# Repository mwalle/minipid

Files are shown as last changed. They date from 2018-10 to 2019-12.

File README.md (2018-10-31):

# minipid - an attiny based heating controller

minipid is an open source hardware and software PI controller. It's design
goal is to be cheap and easy to build. It was originally developed for the
Rancilio Siliva.

## Warning

This project uses dangerous mains voltage. Be careful!

## Features

 * cheap
 * configurable parameters, like target temperature, Kp and Ki and controlling range
 * auto off
 * built in self test
 * configuration interface on the serial line
 * display support
 * ISP support
 * fast PI controller
 * emergency off
 * error blinking, if no display is connected
 * easy to use, easy to built
 * dump parameters like temperature and output value to serial console
 * automatically detects connected display
 * open hardware and open source software

## License

The firmware is licensed under the GNU Public License version 2 and the
hardware is licensed under CERN OHL v.1.2. See `COPYING.firmware` and
`COPYING.hardware` for the complete license.

## Hardware Errata

 - [ ] SDA and SCL pull-downs are missing

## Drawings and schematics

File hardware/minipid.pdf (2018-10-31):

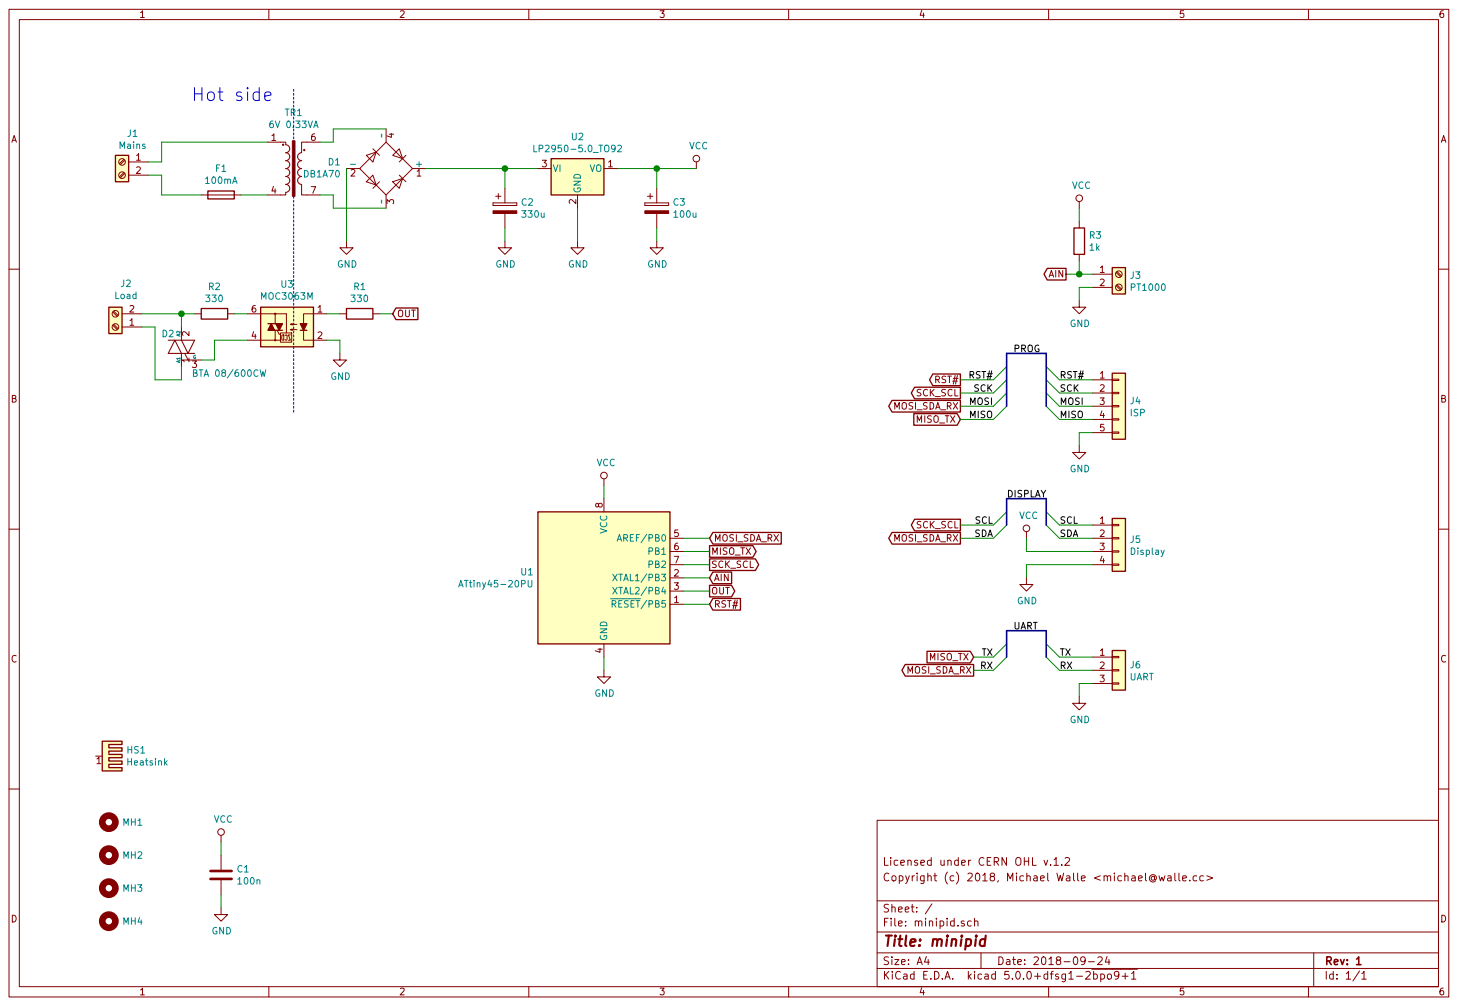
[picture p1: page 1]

SCK_SCL RST# RST# SCK MOSI MISO

ISP RST# MISO MOSI SCK

Licensed under CERN OHL v.1.2
File: minipid.sch Sheet: / Copyright (c) 2018, Michael Walle <michael@walle.cc>

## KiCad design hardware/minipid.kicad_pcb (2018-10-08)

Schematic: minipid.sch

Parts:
C1: 100n; C_Disc_D4.3mm_W1.9mm_P5.00mm
C2: 330u; CP_Radial_D8.0mm_P3.50mm
C3: 100u; CP_Radial_D6.3mm_P2.50mm
D1: DB1A70; Diode_Bridge_DIP-4_W7.62mm_P5.08mm
D2: BTA 08/600BW; TO-220-3_Horizontal_TabDown
F1: 100mA; Fuseholder_TR5_Littlefuse_No560_No460
HS1: Heatsink; Heatsink_35x26mm_1xFixation3mm_Fischer-SK486-35
J1: Mains; TerminalBlock_RND_205-00001_1x02_P5.00mm_Horizontal
J2: Load; TerminalBlock_RND_205-00001_1x02_P5.00mm_Horizontal
J3: PT1000; TerminalBlock_RND_205-00001_1x02_P5.00mm_Horizontal
J4: ISP; PinHeader_1x05_P2.54mm_Vertical
J5: Display; PinHeader_1x04_P2.54mm_Vertical
J6: UART; PinHeader_1x03_P2.54mm_Vertical
MH1, MH2, MH3, MH4: MountingHole; MountingHole_3.2mm_M3
R1, R2: 330; R_Axial_DIN0207_L6.3mm_D2.5mm_P10.16mm_Horizontal
R3: 1k; R_Axial_DIN0207_L6.3mm_D2.5mm_P10.16mm_Horizontal
TR1: 6V 0.33VA; Transformer_Breve_TEZ-22x24
U1: ATtiny45-20PU; DIP-8_W7.62mm
U2: LP2950-5.0_TO92; TO-92_Inline
U3: MOC3063M; DIP-6_W7.62mm

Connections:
AIN: J3.1, R3.2, U1.2 (XTAL1/PB3)
GND: C1.2, C2.2, C3.2, D1.2, J3.2, J4.5, J5.4, J6.3, U1.4 (GND), U2.2 (GND), U3.2
MISO_TX: J4.4, J6.1, U1.6 (PB1)
MOSI_SDA_RX: J4.3, J5.2, J6.2, U1.5 (AREF/PB0)
unnamed: C2.1, D1.1, U2.3 (VI)
unnamed: D1.3, TR1.7
unnamed: D1.4, TR1.6
unnamed: D2.1, J2.1
unnamed: D2.2, J2.2, R2.1
unnamed: D2.3, U3.4
unnamed: F1.1, J1.2
unnamed: F1.2, TR1.4
unnamed: J1.1, TR1.1
unnamed: R1.1, U3.1
unnamed: R2.2, U3.6
OUT: R1.2, U1.3 (XTAL2/PB4)
RST#: J4.1, U1.1 (~RESET~/PB5)
SCK_SCL: J4.2, J5.1, U1.7 (PB2)
VCC: C1.1, C3.1, J5.3, R3.1, U1.8 (VCC), U2.1 (VO)

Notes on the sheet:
Hot side

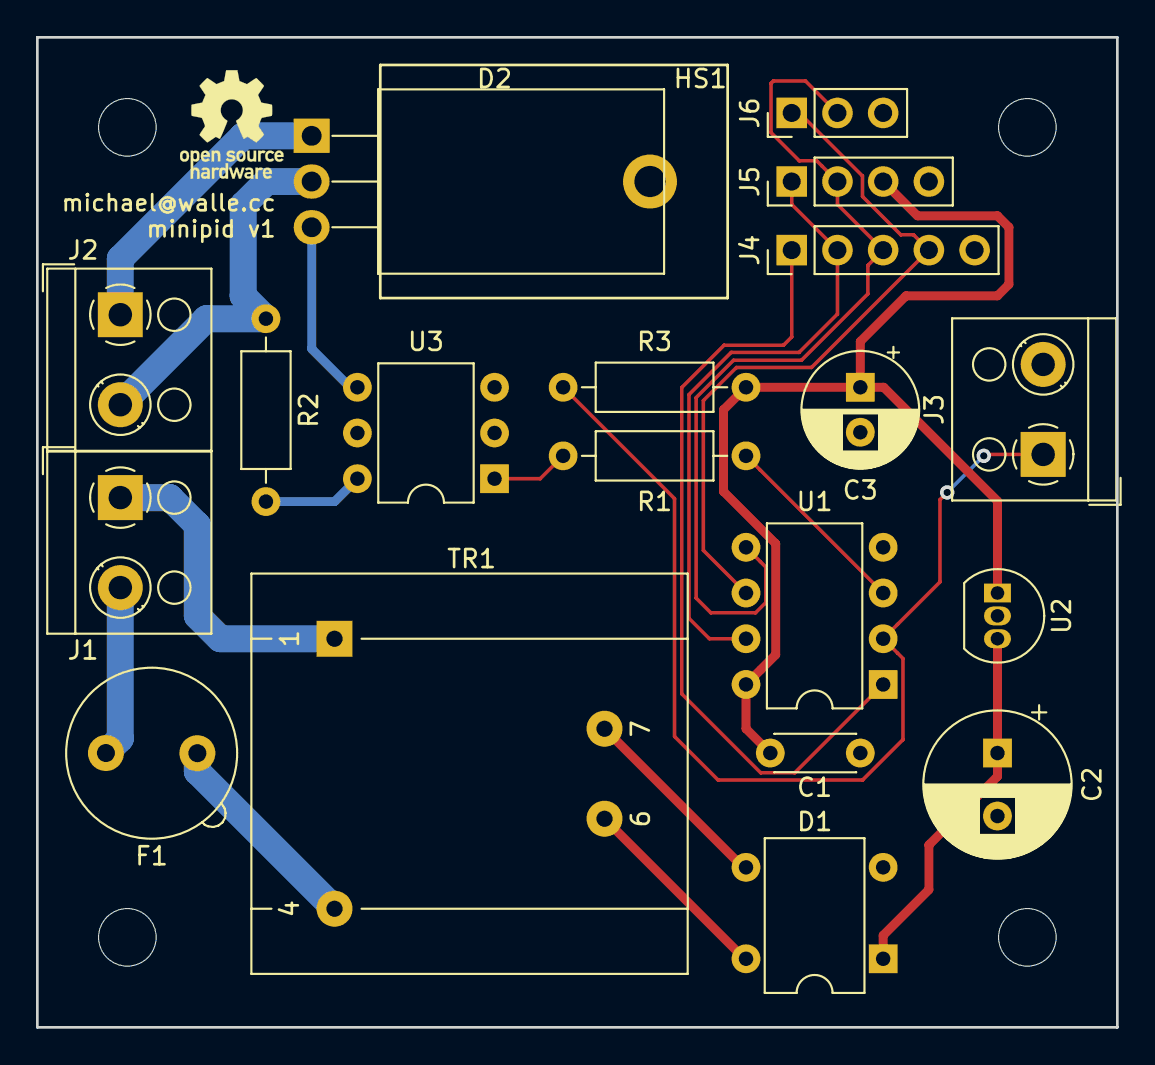
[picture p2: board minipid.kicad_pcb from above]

Board: 2 copper layers, 60.0 x 55.0 mm, 24 parts (0 on the bottom side), 19 nets.

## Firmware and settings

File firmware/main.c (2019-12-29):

/*
 * minipid - attiny-based heating controller
 * Copyright (c) 2018, Michael Walle <michael@walle.cc>
 *
 * SPDX-License-Identifier: GPL-2.0
 */

#include <stdio.h>
#include <stdbool.h>
#include <string.h>
#include <stdlib.h>
#include <avr/io.h>
#include <avr/interrupt.h>
#include <avr/pgmspace.h>
#include <util/atomic.h>
#include <util/delay.h>

#include "usi.h"
#include "adc.h"
#include "pt1000.h"
#include "pid.h"
#include "config.h"

#define VERSION "0.1"
#ifndef FORCE_CLI_ENABLED
#define FORCE_CLI_ENABLED 0
#endif

static volatile uint8_t __pwm_steps;
static void pwm_set(uint8_t steps)
{
	__pwm_steps = steps;
}

static void pwm_init(void)
{
	__pwm_steps = 0;
	PORTB &= _BV(PB4);
	DDRB |= _BV(PB4);
}

static void pwm_off(void)
{
	__pwm_steps = 0;
	PORTB &= ~_BV(PB4);
}

static volatile uint16_t __uptime;
static volatile uint32_t __millis;

uint16_t uptime(void)
{
	uint16_t _uptime;
	ATOMIC_BLOCK(ATOMIC_FORCEON) {
		_uptime = __uptime;
	}
	return _uptime;
}

uint32_t millis(void)
{
	uint32_t _millis;
	ATOMIC_BLOCK(ATOMIC_FORCEON) {
		_millis = __millis;
	}
	return _millis;
}

ISR(TIM1_COMPA_vect)
{
	static uint8_t cycle = 0;

	/* only set the pwm output of the beginning of the cycle */
	if (__pwm_steps && cycle == 0)
		PORTB |= _BV(PB4);
	else if (cycle >= __pwm_steps)
		PORTB &= ~_BV(PB4);

	__millis += 10;

	if (cycle == 99 || cycle == 199)
		__uptime++;

	if (++cycle >= 200)
		cycle = 0;
}

static void timer1_init(void)
{
	/*
	 * Setup Timer1 to 10ms (actually 9.98ms).
	 *
	 * The system clock is 8 MHz, use the 512 prescaler and a counter
	 * value of 156.
	 *
	 */
	/* CTC mode, prescaler to 512 */
	TCCR1 = _BV(CTC1) | _BV(CS13) | _BV(CS11);
	OCR1A = (F_CPU / 512 / 100);
	OCR1C = (F_CPU / 512 / 100);

	/* enable timer interrupt */
	TIMSK |= _BV(OCIE1A);
}

static void timer1_stop(void)
{
	TCCR1 = 0;
}

enum {
	ERROR_INVALID_SDA_SCL_STATE = 1,
	ERROR_SENSOR_UNCONNECTED = 2,
	ERROR_SENSOR_SHORTED = 3,
	ERROR_EMERGENCY_OFF = 4,
};

static void reset(void) __attribute__((noreturn));
static void reset(void)
{
	WDTCR = _BV(WDE);
	while (true);
}

static void configuration_mode(void)
{
	const char *buf;
	char c;

	/* turn output off */
	pwm_off();

	uart_puts_P(PSTR("Configuration mode, output disabled.\n"));

	while (true) {
again:
		uart_get_buf();
		uart_puts_P(PSTR("config> "));
		while (true) {
			uart_poll();
			c = uart_getc();

			if (c == '\r') {
				uart_putc('\n');
				break;
			}

			if (c == '\b' || c == 127) {
				uart_puts("Backspace not supported. Try again.\n");
				goto again;
			}

			/* echo back */
			uart_putc(c);
		}

		buf = uart_get_buf();
		if (buf[0] == '.') {
			config_scan_input(buf + 1);
			config_dump();
		} else if (buf[0] == '\r') {
			continue;
		} else if (!strncmp_P(buf, PSTR("reset"), 5)) {
			reset();
		} else if (!strncmp_P(buf, PSTR("dump"), 4)) {
			config_dump();
		} else if (!strncmp_P(buf, PSTR("save"), 4)) {
			uart_puts_P(PSTR("Saving config to EEPROM.\n"));
			config_save();
		} else if (!strncmp_P(buf, PSTR("exit"), 4)) {
			uart_puts_P(PSTR("Exitting config mode.\n"));
			return;
		} else if (!strncmp_P(buf, PSTR("help"), 4)) {
			uart_puts_P(PSTR(
						"Available commands:\n"
						".<P> <V> - set parameter <P> to value <V>\n"
						"dump  - show config\n"
						"save  - show config\n"
						"reset - reset controller\n"
						"exit  - show config\n"));
		} else {
			uart_puts_P(PSTR("Unknown command, try 'help'.\n"));
		}
	}
}

static void blink_errorcode(uint8_t code) __attribute__((noreturn));
static void blink_errorcode(uint8_t code)
{
	char buf[8];
	int i;

	/* turn output off */
	timer1_stop();
	PORTB &= ~_BV(PB4);

	while (true) {
		if (uart_getc() == '\r')
			configuration_mode();

		/* output error on UART */
		uart_puts_P(PSTR("ERR"));
		uart_puts(itoa(code, buf, 10));
		uart_puts_P(PSTR("\n"));

		/* two short blinks */
		for (i = 0; i < 2; i++) {
			PORTB |= _BV(PB4);
			_delay_ms(50);
			PORTB &= ~_BV(PB4);
			_delay_ms(300);
		}

		_delay_ms(500);
		/* error code */
		for (i = 0; i < code; i++) {
			PORTB |= _BV(PB4);
			_delay_ms(100);
			PORTB &= ~_BV(PB4);
			_delay_ms(500);
		}

		/* 10s pause */
		_delay_ms(10000);
	}
}

static void display_init(void)
{
	uint8_t buf;

	/* dummy transfer */
	buf = 0x00;
	twi_transfer(&buf, 1);

	/* display on, max brightness */
	buf = 0xf1;
	twi_transfer(&buf, 1);
}

static uint8_t display_digit(uint8_t i)
{
	static const uint8_t digits[] PROGMEM = {
		0b11111100,    // 0
		0b01100000,    // 1
		0b11011010,    // 2
		0b11110010,    // 3
		0b01100110,    // 4
		0b10110110,    // 5
		0b10111110,    // 6
		0b11100000,    // 7
		0b11111110,    // 8
		0b11110110,    // 9
		0b11101110,    // A
		0b00111110,    // b
		0b10011100,    // C
		0b01111010,    // d
		0b10011110,    // E
		0b10001110,    // F
		0b00000000,    // all off
		0b11000110,    // deg
	};

	return pgm_read_byte(&(digits[i]));
}

static void display_errorcode(uint8_t code)
{
	static uint8_t buf[5];

	buf[0] = 0x02;
	twi_transfer(buf, 1);

	buf[0] = '\x03';
	buf[1] = display_digit(14);
	buf[2] = display_digit(0);
	buf[3] = display_digit(0);
	buf[4] = display_digit(code % 10);

	twi_transfer(buf, 5);
}

static void display_degc(uint8_t val)
{
	static uint8_t buf[5];

	buf[0] = 0x02;
	twi_transfer(buf, 1);

	buf[0] = '\x03';
	if (val < 100)
		buf[1] = display_digit(16);
	else
		buf[1] = display_digit((val / 100) % 10);
	if (val < 10)
		buf[2] = display_digit(16);
	else
		buf[2] = display_digit((val / 10) % 10);
	buf[3] = display_digit(val % 10);
	buf[4] = display_digit(17);

	twi_transfer(buf, 5);
}

static void print_statusline(int16_t degc, int16_t pwm, bool auto_off)
{
	char buf[8];
	uart_puts(itoa(uptime(), buf, 10));
	uart_puts_P(PSTR(" "));
	uart_puts(itoa(degc / 10, buf, 10));
	uart_puts_P(PSTR("."));
	uart_puts(itoa(degc % 10, buf, 10));
	uart_puts_P(PSTR(" "));
	uart_puts(itoa(pwm, buf, 10));
	uart_puts_P(PSTR(" "));
	if (auto_off)
		uart_puts_P(PSTR("auto-off "));
	uart_puts_P(PSTR("\n"));
}

int main(void)
{
	bool cli_enabled = false;
	bool display_enabled = false;
	bool auto_off = false;

	uint16_t _uptime;
	uint32_t _millis;
	uint16_t last_uptime = UINT16_MAX;
	uint32_t next_sample_time = 0;
	uint16_t adc_val;
	int16_t degc;
	int16_t error;
	int16_t out;
	uint16_t emergency_off_adc_val;
	uint8_t errorcode;

	/* clear watchdog */
	MCUSR = 0;
	WDTCR |= _BV(WDCE) | _BV(WDE);
	WDTCR = 0;

	config_init();
	emergency_off_adc_val = degc2adc(config->emergency_off);

	/*
	 * We have three cases for PB2 (SCL) and PB0 (SDA/UART_DI).
	 *
	 * If I2C is connected, there will be a pull-up on both lines. If UART is
	 * connected the UART_DI will be high because it is the default line state.
	 *
	 * | PB2  | PB0  | Description                                                |
	 * +------+------+------------------------------------------------------------+
	 * | low  | low  | Nothin is connected. Disable display and cli are disabled. |
	 * | high | high | I2C is connected. Enable display.                          |
	 * | low  | high | UART is connected. Enable cli.                             |
	 * | high | low  | Invalid state. Turn off, display error.                    |
	 */

	switch (PINB & (_BV(PB2) | _BV(PB0))) {
	case 0:
		break;
	case _BV(PB2):
		blink_errorcode(ERROR_INVALID_SDA_SCL_STATE);
		break;
	case _BV(PB0):
		cli_enabled = true;
		break;
	case _BV(PB2) | _BV(PB0):
		display_enabled = true;
		break;
	}

	if (FORCE_CLI_ENABLED)
		cli_enabled = true;

	if (cli_enabled)
		uart_rx_tx_init();
	else
		uart_tx_twi_init();

	adc_init();
	if (display_enabled)
		display_init();
	pwm_init();
	timer1_init();
	pid_init();

	sei();

	uart_puts_P(PSTR("minipid v" VERSION "\n"));

	if (cli_enabled) {
		uart_puts_P(PSTR("UART detected. Press return to enter configuration mode.\n"));
	}

	while (true) {
		adc_val = adc_get();
		if (adc_val == ADC_OPEN) {
			errorcode = ERROR_SENSOR_UNCONNECTED;
		} else if (adc_val == ADC_SHORT) {
			errorcode = ERROR_SENSOR_SHORTED;
		} else if (adc_val >= emergency_off_adc_val) {
			errorcode = ERROR_EMERGENCY_OFF;
		} else {
			errorcode = 0;
		}

		if (errorcode) {
			if (display_enabled)
				display_errorcode(errorcode);
			blink_errorcode(errorcode);
		}
		degc = adc2degc(adc_val);

		_uptime = uptime();
		if (_uptime != last_uptime) {
			last_uptime = _uptime;

			if (display_enabled) {
				display_degc(degc / 10);
			}
			print_statusline(degc, out, auto_off);
		}

		if (uart_getc() == '\r') {
			configuration_mode();
			auto_off = false;
			emergency_off_adc_val = degc2adc(config->emergency_off);
			pid_init();
		}

		_millis = millis();
		if (_millis > next_sample_time) {
			next_sample_time = _millis + config->sample_time_ms;

			error = config->set_point - degc;
			out = pid_update(error, degc);
			if (out > 200) {
				out = 200;
			} else if (out < 0) {
				out = 0;
			}
			if (auto_off)
				out = 0;
			pwm_set(out);
		}

		if (config->auto_off_time && _uptime >= config->auto_off_time)
			auto_off = true;
	}

	return 0;
}

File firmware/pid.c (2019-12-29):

/*
 * minipid - attiny-based heating controller
 * Copyright (c) 2018, Michael Walle <michael@walle.cc>
 *
 * SPDX-License-Identifier: GPL-2.0
 */

#include <stdio.h>
#include <stdint.h>
#include <stdlib.h>
#include <avr/pgmspace.h>

#include "pid.h"
#include "usi.h"
#include "config.h"

struct pid {
	int16_t p_gain;
	int16_t i_gain;
	int16_t band;
	//int16_t max_error;

	int16_t i_sum;
	int16_t i_min;
	int16_t i_max;

	//int16_t kt;
	//int16_t out_min;
	//int16_t out_max;
	//int16_t out_last;

#ifdef PID_D
	int16_t d_gain;
	int16_t d_last;
#endif
};

struct pid _pid, *pid = &_pid;

void pid_init(void)
{
	pid->p_gain = config->kp;
	pid->band = config->band;
	//pid->max_error = INT16_MAX / (pid->p_gain + 1);

	pid->i_gain = config->ki;
	pid->i_min = config->i_min;
	pid->i_max = config->i_max;

	//pid->kt = 5;
	//pid->out_min = 0;
	//pid->out_max = 200;

#ifdef PID_D
	pid->d_gain = config->d_gain;
#endif

	pid_reset();
}

void pid_reset(void)
{
	pid->i_sum = 0;
	//pid->out_last = 0;
#ifdef PID_D
	pid->d_last = INT16_MIN;
#endif
}

uint32_t millis(void);
static void print_pid_statusline(int16_t error, int32_t p, int32_t i, int32_t d, int32_t ret)
{
	char buf[12];
	uart_puts_P(PSTR("error="));
	uart_puts(itoa(error, buf, 10));
	uart_puts_P(PSTR(" p="));
	uart_puts(ltoa(p, buf, 10));
	uart_puts_P(PSTR(" i="));
	uart_puts(ltoa(i, buf, 10));
	uart_puts_P(PSTR(" d="));
	uart_puts(ltoa(d, buf, 10));
	uart_puts_P(PSTR(" ret="));
	uart_puts(ltoa(ret, buf, 10));
	uart_puts_P(PSTR(" i_sum="));
	uart_puts(itoa(pid->i_sum, buf, 10));
	uart_puts_P(PSTR("\n"));
}

int16_t pid_update(int16_t error, int16_t position)
{
	int32_t ret, p, i, d;

	if (error < -pid->band)
		return INT16_MIN;
	else if (error > pid->band)
		return INT16_MAX;

#if 0
	/* TBD limit error to prevent overflow */
	if (error > pid->max_error)
		error = pid->max_error;
	else if (error < -pid->max_error)
		error = -pid->max_error;
#endif

	p = (int32_t)pid->p_gain * error;

	/* account error within limits */
	i = (int32_t)pid->i_sum + ((int32_t)pid->i_gain * error * config->sample_time_ms / 1000);
#if 0
	if (pid->out_last > pid->out_max) {
		//printf("remove %d..", pid->i_sum);
		pid->i_sum -= (pid->out_last - pid->out_max) * pid->kt;
		//printf("%d\n", pid->i_sum);
	} else if (pid->out_last < pid->out_min) {
		//printf("add %d..", pid->i_sum);
		pid->i_sum += (pid->out_min - pid->out_last) * pid->kt;
		//printf("%d\n", pid->i_sum);
	}
#else
	if (i > pid->i_max)
		i = pid->i_max;
	else if (i < pid->i_min)
		i = pid->i_min;
#endif

#if PID_D
	if (pid->d_last != INT16_MIN)
		d = pid->d_gain * (pid->d_last - position);
	else
		d = 0;
	pid->d_last = position;
#else
	d = 0;
#endif

	ret = (p + i + d) >> PID_SCALING_SHIFT;
	pid->i_sum = i;

	if (config->flags & FLAGS_DEBUG_PID)
	{
		static uint32_t next_tout = 0;
		if (millis() > next_tout) {
			next_tout = millis() + 1000;
			print_pid_statusline(error, p, i, d, ret);
		}
	}

	if (ret > INT16_MAX)
		ret = INT16_MAX;
	else if (ret < INT16_MIN)
		ret = INT16_MIN;

	//pid->out_last = ret;
	return ret;
}

#ifdef UT_ENABLED
static float val = 200;
static int16_t read_val()
{
	return val;
}
static void drive_val(int16_t drive)
{
	static float last = 0;
	if (drive > 200)
		drive = 200;
	else if (drive < 0)
		drive = 0;

	/* delay line */
	val += last;

	last = drive * 0.1;

	val -= 0.4;
}

int main(void)
{
	int i = 0;
	int16_t position;
	int16_t setpoint = 1050;
	int16_t drive;

#define k (1 << PID_SCALING_SHIFT)
	config->kp = 0.75 * k;
	config->band = 100;

	config->ki = 0.1 * k;
	config->i_min = 0 * k;
	config->i_max = 10 * k;
	config->sample_time_ms = 100;

	pid_init();

	while(i++ < 1000) {
		position = read_val();
		drive = pid_update(setpoint - position, position);
		drive_val(drive);
		printf("%03i drive=%d position=%d\n", i, drive, position);
	}
}
#endif

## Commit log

2018-10-16 adc: convert to fixed point arithmetic
    [main.c]
2018-10-16 pid: major update
    Make derivative part a compile time option and use int16_t for the
    integrator. Remove max_error check, because internally, we calculate
    with 32 bit now. Remove float data types.
2018-10-16 pid: add simulation
2018-10-16 usi: add uart_puts() and uart_puts_P()
    Also, send additional carriage return on newline.
2018-10-16 main: get rid of printf()
2018-10-16 main: print version
2018-10-18 adc: move adc stuff into own module
2018-10-18 tests: move config tests to tests/
    We use the glib testing framework to make unit tests.
2018-10-18 main: print statusline periodically
2018-10-18 adc: fix init
2018-10-18 main: enable pid controller
2018-10-19 usi: new rx handling
    There is now a RX buffer, which saturates at the end. uart_getc() will
    still return the last received character. But now it is also possible to
    poll for a received character using uart_poll().
2018-10-19 main: fix undefined function
    [main.c]
2018-10-19 main: use sample_time_ms configuration parameter
    Introduce the millis() function which counts milliseconds. Also fix the
    access to uptime by using a dedicated function.
    [main.c]
2018-10-19 adc: move pt1000 conversions to own module
    This will ease the testing.
2018-10-21 usi: fix rx buffer
    The first bit was never written, therefore the buffer was always empty.
    [usi.c]
2018-10-21 main: fix uptime and sample time
    [main.c]
2018-10-21 pid: call pid_init()
    This was missing, thus the controller wasn't working.
    [main.c, pid.c]
2018-10-30 pid: use scaled value for i_sum
    In this case, finer increments are possible. Also take the sample time
    into account.
2018-10-31 pid: add statusline and debug flag
2018-10-31 hardware: fix Triac name
    [minipid.sch]
2018-10-31 add copyright and license
    [minipid.sch]
2018-10-31 hardware: add schematics and gerber files
    [minipid.drl, minipid.gbl, minipid.gbo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]
2018-12-09 main: add auto power-off support
2018-12-09 main: goto error state on sensor failure
    If the sensor is either not connected or it is shorted go into error
    state.
    [main.c]
2018-12-09 main: enter configuration mode in error state
    In case the user might have something misconfigured, there is no way to
    enter configuration mode once the controller is in error state. Fix
    this.
    [main.c]
2019-12-29 main: add reset command
    [main.c]
2019-12-29 usi: init uart idx in every case
2019-12-29 main: show error code on i2c display
    [main.c]
2019-12-29 pid: cast to int32 to prevent overflow
    [pid.c]
